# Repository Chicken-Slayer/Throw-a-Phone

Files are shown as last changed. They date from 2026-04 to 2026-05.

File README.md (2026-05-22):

# Throw-a-Phone
Have you ever forgotten your phone at home, and just kept your SIM card along? Me too!
This device aims to solve this common problem faced by us in our daily lives.

In all seriousness, this is a device for people who need absolutely no distractions, or simply a cheap device that can be bought to simply make phone calls without any drama.

## How it works:
Inside the case, there is an ESP32 C3 SUPERMINI, which is compact and affordable - perfect for this use case. Basically, the device uses a 12 key matrix as input, which can be used to enter phone numbers and answer/end calls. The calls are handled using a SIM800L GSM module connected to an external antenna. Due to the hardware used, it can only support 2G networks, which are outdated and may not be available everywhere. 

## PCB:
Here's the Schematic and the PCB:

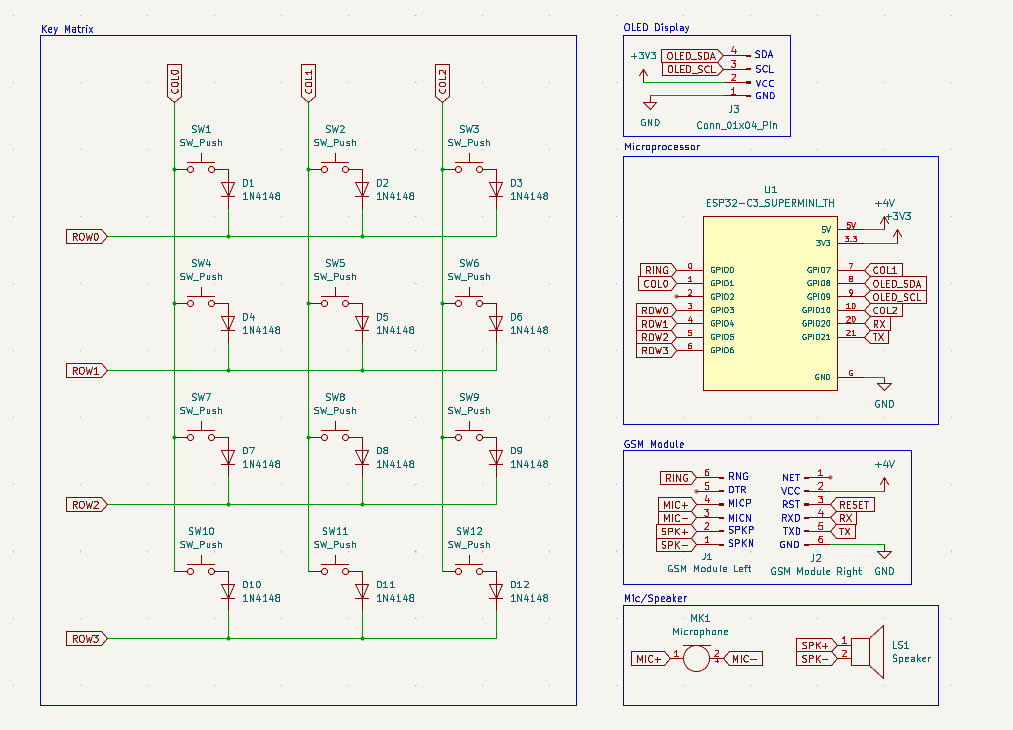
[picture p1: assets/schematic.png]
schematic


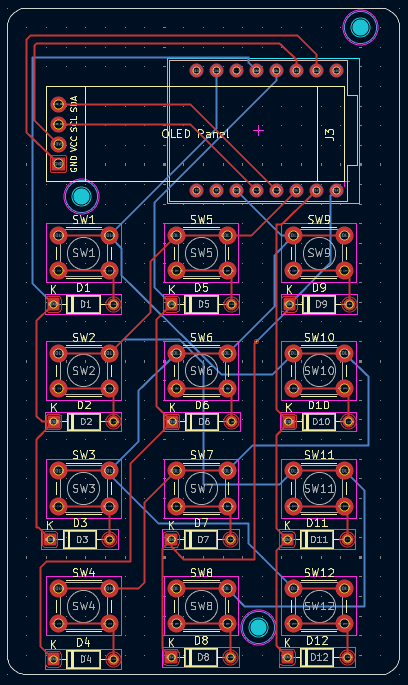
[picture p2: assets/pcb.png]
pcb


## Enclosure:
The components are placed within a 3D printed enclosure. The PCB is held in place with round inserts set in place in both the PCB and the Enclosure. 

It has two separate pieces: 
- The top cover, featuring space for the keys, power switch, screen, and audio I/O
- The base, which has obtrusions designed to hold the PCB in place, as well as clearance for an external antenna and charging port.

The two pieces are secured using hot glue.

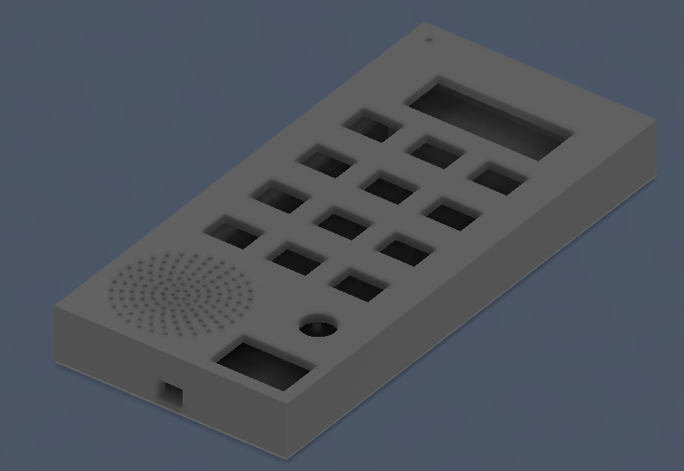
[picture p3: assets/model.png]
model


## Firmware:
The device is coded in C, and makes/receives phone calls by communicating with the GSM module through the UART interface. A key matrix is used to input the numbers and Adafruit libraries are used to control the OLED Display. Different states of the phone have been defined, in which different output is displayed on the OLED.

## Features:
- Making and receiving phone calls

## Replication Guide:
This project is quite easy to replicate hardware-wise, but the software part comes out to be more complicated.
1. Start off by wiring the charging board output to the rocker switch, and then the switch to the ESP32 and the GSM module. The GSM module cannot run on 3.3V supplied by ESP32, so it needs to be powered directly by the battery.
2. Solder the buttons and the OLED display on to the PCB, making sure that the diodes are in the right direction (COL2ROW).
3. Solder the ESP32 module to the PCB and connect the RX, TX and GPIO0 pins to the corresponding ones on the GSM modules.
4. Wire the speaker and the microphone directly to the GSM module and connect the PCB antenna (comes bundled with GSM module).
5. Connect the battery to the charging board power input. Make sure to check polarity.
6. Load up the firmware on to the ESP32 board, making sure to check the pin definitions in the code.
7. Secure the components in place, holding the PCB using the round insertions in the case, and hot gluing remaining components in their respective places. On the top part of the case, space has been given for inserting the microphone, speaker, and rocker switch. There are holes on the bottom part of the case to route the PCB antenna outside and connect the charging module to a USB cable. 

## BOM:
| Product Name | Product Link | Unit Price | Amount | Total  | Remarks |
|---|---|---|---|---|---|
| PCB | https://jlcpcb.com/ | $2.00 | 1 | $11.47 | |
| SIM800L GPRS GSM Module | https://roboticsdna.in/product/sim800l-module/ | $3.10 | 1 | $4.04  | Delivery costs and taxes apply |
| 3.7V 1500 mAh LiPo Battery | https://robu.in/product/1500mah-pcm-protected-micro-li-po-battery | $2.96 | 1 | $2.96  | |
| Tactile Push Button Switch | https://robu.in/product/6x6x5-tactile-push-button-switch | $0.014 | 12 | $0.28  | Only in packs of 10 |
| Microphone | https://robu.in/product/microphone-97mm-pack-of-3 | $0.20 | 1 | $0.58  | Only in packs of 3 |
| TP4056 Li-ion battery charging board | https://robu.in/product/tp4056-1a-lipo-battery-charging-board-micro-usb-with-current-protection | $0.12 | 1 | $0.12  | |
| 28mm Trumpet Speaker | https://robu.in/product/0-5w-8ohm-trumpet-speaker-diameter-28mm | $0.30 | 1 | $0.30  | |
| SPST Rocker Switch | https://robu.in/product/spst-rocker-switch-pack-of-3 | $0.15 | 1 | $0.15  | |
| ESP32-C3 SUPERMINI | https://robu.in/product/esp32-c3-development-board-with-soldering | $2.59 | 1 | $2.59  | |
| 0.91 inch I2C OLED Display | https://roboticsdna.in/product/0-91-inch-iic-4-pin-oled-display-module-ssd1306-white/ | $1.66 | 1 | $2.60  | Delivery costs and taxes apply |
| M2x10mm CSK Countersunk Philips head bolt| https://robu.in/product/easymech-ss-304-csk-countersunk-philips-head-m2-x-10-mm-bolt-25-pcs/| $1.48 | 4 | $1.48  | Only in packs of 25 |
| | | | TOTAL  | $25.09 | |
## Zine:

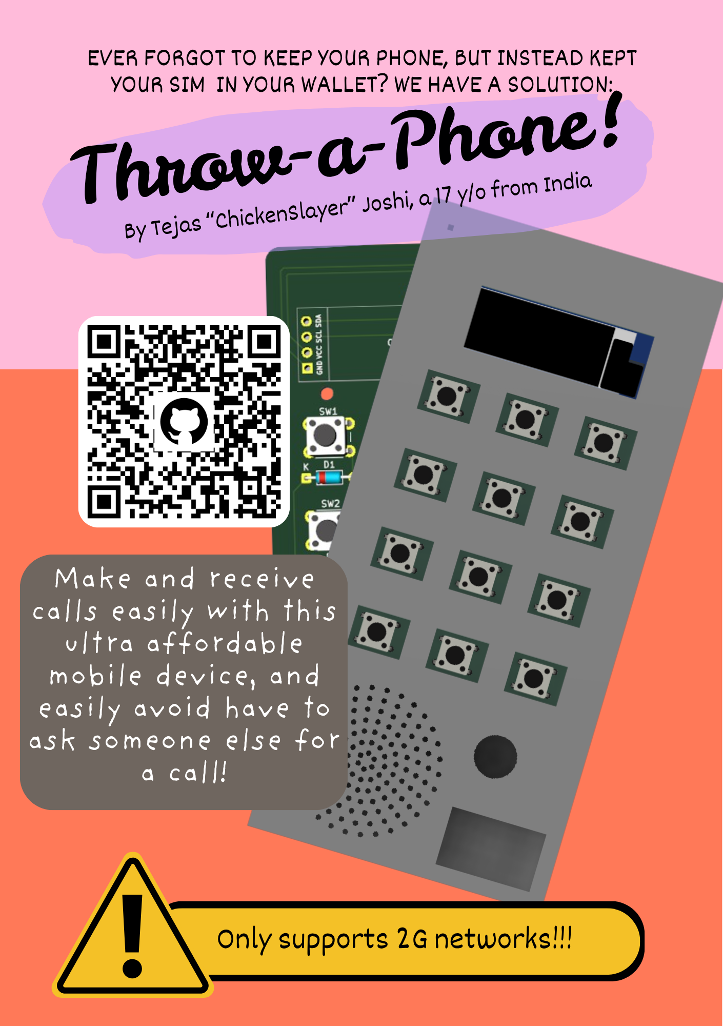
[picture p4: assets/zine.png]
zine


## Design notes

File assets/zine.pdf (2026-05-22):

## EVER FORGOT TO KEEP YOUR PHONE, BUT INSTEAD KEPT YOUR SIM IN YOUR WALLET? WE HAVE A SOLUTION:

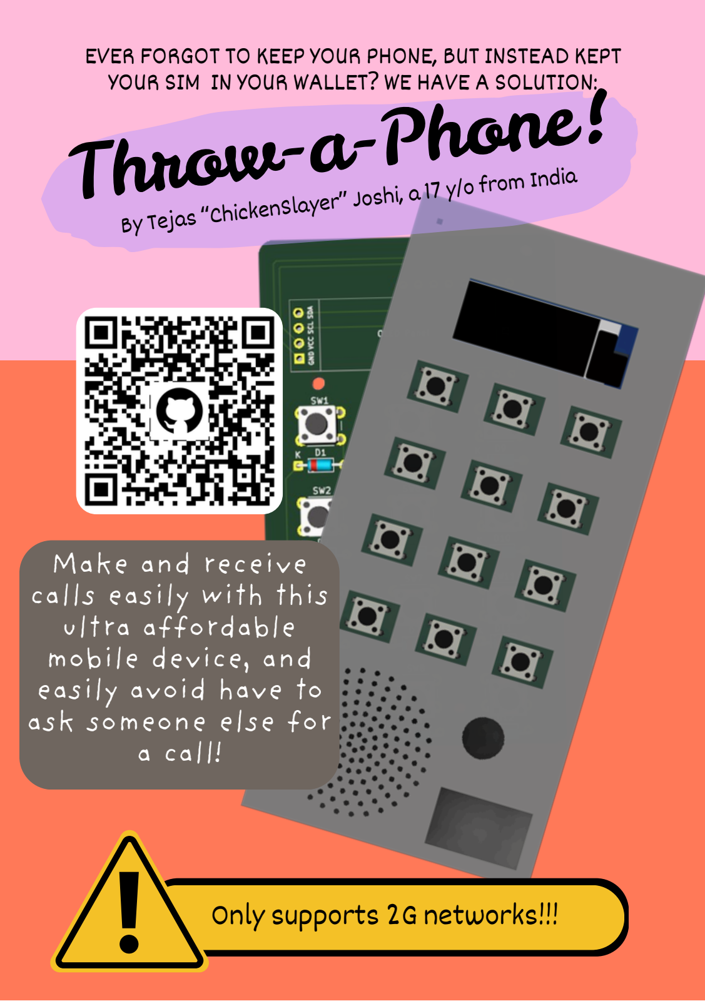
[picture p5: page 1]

Make and receive
calls easily with this
ultra affordable
mobile device, and
easily avoid have to
ask someone else for
a call!

## Only supports 2G networks!!!

# Throw-a-Phone!

## By Tejas

## “ChickenSlayer” Joshi, a 17 y/o from India

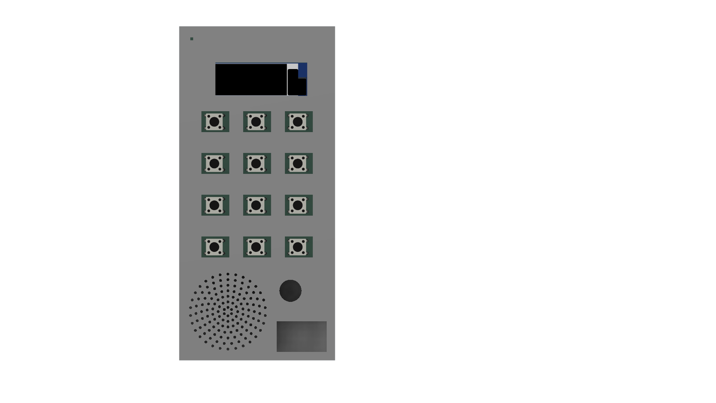
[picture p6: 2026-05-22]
assets/render.png

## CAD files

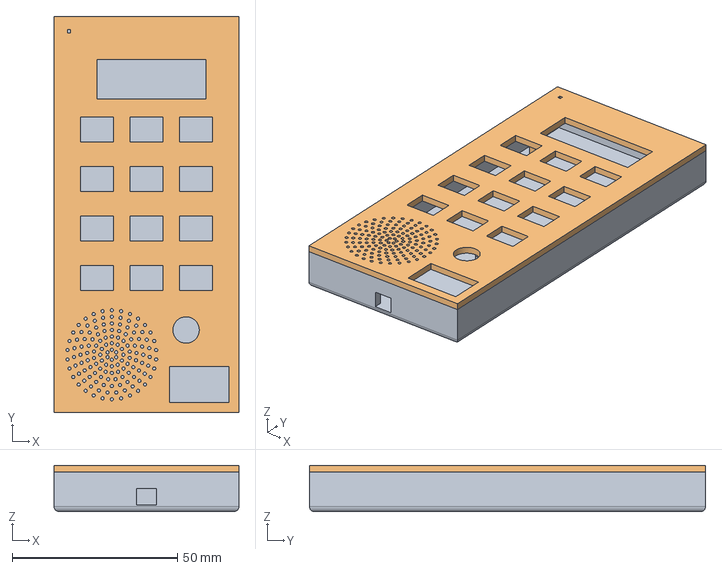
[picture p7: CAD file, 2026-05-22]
Model/Complete.step
56.0 x 120.0 x 14.0 mm

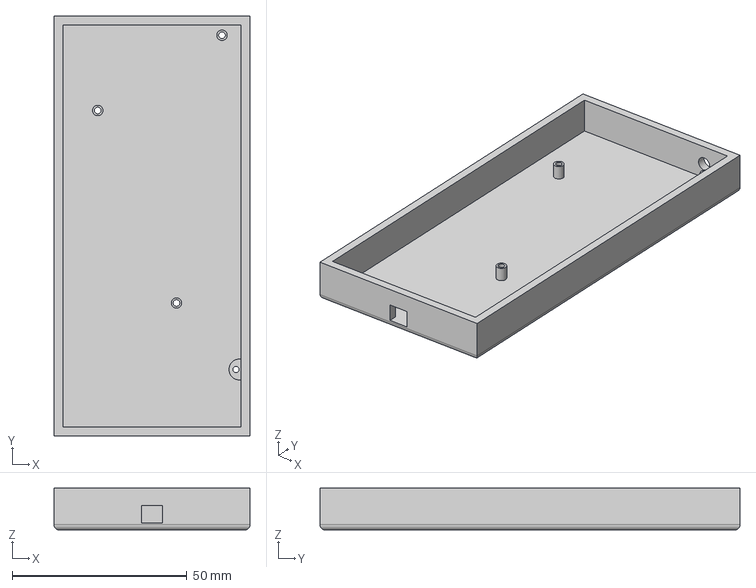
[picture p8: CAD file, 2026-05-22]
Model/Bottom.step
56.0 x 120.0 x 12.0 mm

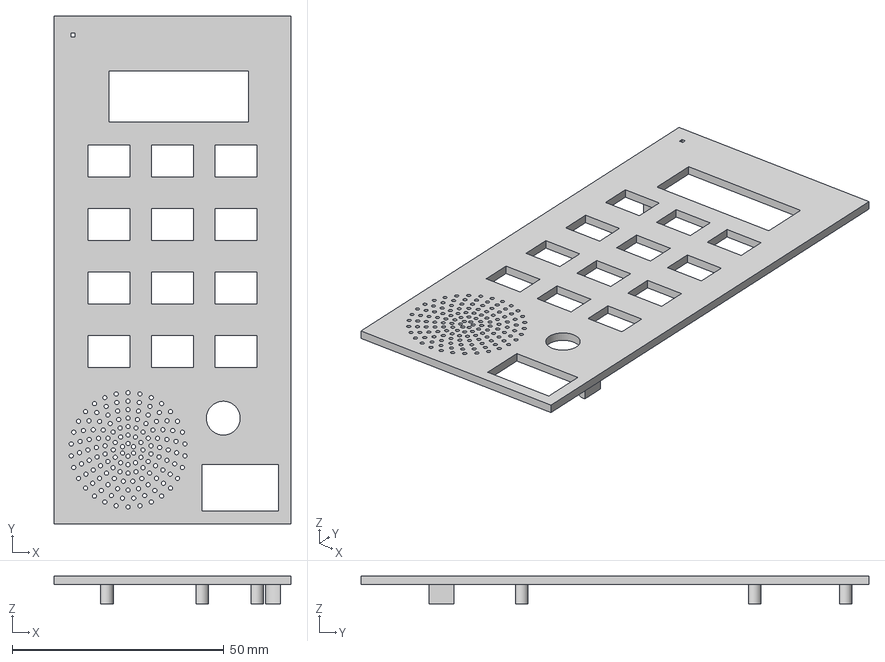
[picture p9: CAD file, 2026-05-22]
production/Top.step
56.0 x 120.0 x 6.50 mm

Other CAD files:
Model/Throw-a-Phone.f3z

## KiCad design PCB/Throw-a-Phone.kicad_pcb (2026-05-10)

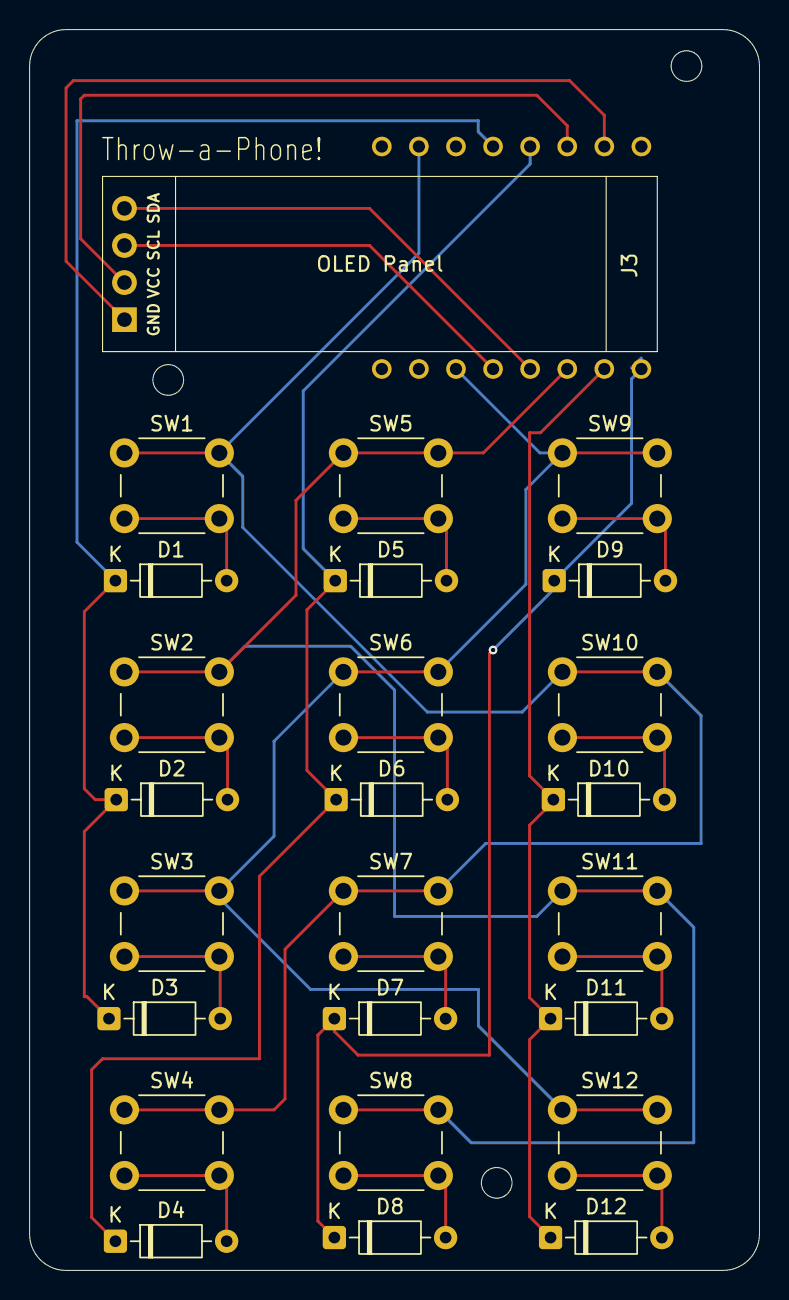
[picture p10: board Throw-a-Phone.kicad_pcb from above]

Board: 2 copper layers, 50.0 x 85.0 mm, 26 parts (1 on the bottom side), 23 nets.

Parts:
D1, D2, D3, D4, D5, D6, D7, D8, D9, D10, D11, D12: 1N4148; D_DO-35_SOD27_P7.62mm_Horizontal
J3: Conn_01x04_Pin; SSD1306-0.91-OLED-4pin-128x32
SW1, SW2, SW3, SW4, SW5, SW6, SW7, SW8, SW9, SW10, SW11, SW12: SW_Push; SW_PUSH_6mm_H5mm
U1: ESP32-C3_SUPERMINI_TH; MODULE_ESP32-C3_SUPERMINI_TH

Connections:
+3V3: J3.2, U1.3.3 (3V3)
COL0: SW1.1, SW4.1, SW7.1, SW10.1, U1.1 (GPIO1)
COL1: SW2.1, SW5.1, SW8.1, SW11.1, U1.7 (GPIO7)
COL2: SW3.1, SW6.1, SW9.1, SW12.1, U1.10 (GPIO10)
GND: J3.1, U1.G (GND)
unnamed: D1.2 (A), SW1.2
unnamed: D2.2 (A), SW2.2
unnamed: D3.2 (A), SW3.2
unnamed: D4.2 (A), SW4.2
unnamed: D5.2 (A), SW5.2
unnamed: D6.2 (A), SW6.2
unnamed: D7.2 (A), SW7.2
unnamed: D8.2 (A), SW8.2
unnamed: D9.2 (A), SW9.2
unnamed: D10.2 (A), SW10.2
unnamed: D11.2 (A), SW11.2
unnamed: D12.2 (A), SW12.2
OLED_SCL: J3.3, U1.9 (GPIO9)
OLED_SDA: J3.4, U1.8 (GPIO8)
ROW0: D1.1 (K), D2.1 (K), D3.1 (K), U1.3 (GPIO3)
ROW1: D4.1 (K), D5.1 (K), D6.1 (K), U1.4 (GPIO4)
ROW2: D7.1 (K), D8.1 (K), D9.1 (K), U1.5 (GPIO5)
ROW3: D10.1 (K), D11.1 (K), D12.1 (K), U1.6 (GPIO6)

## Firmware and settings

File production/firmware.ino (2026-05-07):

/*
Firmware for Throw-a-Phone
By Tejas Joshi "Chicken Slayer"
https://github.com/Chicken-Slayer/Throw-a-Phone
*/

#include <Wire.h>
#include <Adafruit_GFX.h>
#include <Adafruit_SSD1306.h>
#include <SoftwareSerial.h>

// HARDWARE CONFIGURATION:

// display:
#define I2C_SDA 8
#define I2C_SCL 9
#define SCREEN_W 128
#define SCREEN_H 32
#define OLED_RESET -1

Adafruit_SSD1306 display(SCREEN_W, SCREEN_H, &Wire, OLED_RESET);

// GSM Module:
#define SIM_RX 20
#define SIM_TX 21
#define RING 0

SoftwareSerial SIM800L(SIM_RX, SIM_TX);
String simLine = "";

// Key Matrix:
#define ROWS 4
#define COLS 3

const uint8_t ROW_PINS[ROWS] = {3, 4, 5, 6};
const uint8_t COL_PINS[COLS] = {1, 7, 10};

const char KEYMAP[ROWS][COLS] = {
    {'1', '2', '3'},
    {'4', '5', '6'},
    {'7', '8', '9'},
    {'*', '0', '#'}
};

// UART0 is connection to system; UART1 is used for communication to GSM Module

// Phone Configuration:
enum PhoneState {
    ST_IDLE,
    ST_TYPING,
    ST_CALLING,
    ST_INCOMING,
    ST_IN_CALL
};

PhoneState phoneState = ST_IDLE;

String dialingNumber = "";
String callerNumber = "";

// Debounce (limit rate of function execution to improve performance)
unsigned long lastPressTime = 0;
char lastPressKey  = 0;
const unsigned long DEBOUNCE_MS = 220;



// TODO: Properly configure most things:
// - Calling
// - Keys
// - display controls

void setup () {
    Serial.begin(115200);
    Serial.println("[BOOT]Throw-a-Phone starting...")

    // Start display
    Wire.begin(I2C_SDA, I2C_SCL);
    display.setTextColor(SSD1306_WHITE);
    display.clearDisplay();
    display.setTextSize(1);
    display.setCursor(0, 12);
    display.print("Throw-a-Phone initialising...");
    display.display();

    // Starting up the Switch Matrix 
    for (int r = 0; r < ROWS; r++) {
        pinMode(ROW_PINS[r], OUTPUT);
        digitalWrite(ROW_PINS[r], HIGH);
    }
    for (int c = 0; c < COLS; c++) {
        pinMode(COL_PINS[c], INPUT_PULLUP);
    }

    // GSM Module startup
    SIM800L.begin(115200);
    delay(3000);
    SIM800L.println("AT"); 
    updateSerial();
    SIM800L.println("AT+CSQ");
    updateSerial();
    SIM800L.println("AT+CCID");
    updateSerial();
    SIM800L.println("AT+CREG?");
    updateSerial();
    SIM800L.println("AT+CLIP=1");
    updateSerial();
}

void loop() {
    readSIM();

    char key = scanKeys();
    if (key) handleKey(key);

    delay(20);
}


// Note to self: This function is for testing; not to be used in production
void updateSerial() {
    delay(500);
    while (Serial.available())
    {
        SIM800L.write(Serial.read());
    }
    while (SIM800L.available())
    {
        Serial.write(SIM800L.read());
    }
}

void readSIM() {
    while (simSerial.available()) {
        char c = simSerial.read();
        if (c == '\r') continue;  // skip CR
        if (c == '\n') {
        simLine.trim();
        if (simLine.length() > 0) {
            Serial.println("[AT<<] " + simLine);
            processSIMLine(simLine);
        }
        simLine = "";
        } 
        else {
        simLine += c;
        }
  }
}

// Used to scan the key matrix and add the "typing" functionality.
char scanKeys() {
    for (int r = 0; r < ROWS; r++) {
        digitalWrite(ROW_PINS[r], LOW);
        delayMicroseconds(10);

        for (int c = 0; c < COLS; c++) {
            if (digitalRead(COL_PINS[c]) == LOW) {
            char key = KEYMAP[r][c];
            unsigned long now = millis();

            // Accept key if it's a new key or enough time has passed
            bool newKey   = (key != lastPressKey);
            bool debounced = (now - lastPressTime >= DEBOUNCE_MS);

            if (newKey || debounced) {
                lastPressKey  = key;
                lastPressTime = now;
                digitalWrite(ROW_PINS[r], HIGH);

                Serial.printf("[KEY] '%c' pressed\n", key);
                return key;
        }
      }
    }
        digitalWrite(ROW_PINS[r], HIGH);
    }
    lastPressKey = 0;
    return 0;
}

// This function below can seem a little complicated, but it basically just handles the input that we get from the keys on the board.

void handleKey(char key) {
    switch (phoneState) { 
        case ST_IDLE:
            if (key >= '0' && key <= '9') {
                dialNumber = "";
                dialNumber += key;
                phoneState = ST_TYPING;
                updateDisplay();
            }
            break;

        case ST_TYPING:
        if (key >= '0' && key <= '9') {
            if (dialNumber.length() < 15) {
                dialNumber += key;
                updateDisplay();
            }
        } else if (key == '#') {
        // Backspace
            if (dialNumber.length() > 0) {
                dialNumber.remove(dialNumber.length() - 1);
            }
            if (dialNumber.length() == 0) {
                phoneState = ST_IDLE;
            }
            updateDisplay();
        } else if (key == '*') {
        // Dial
            if (dialNumber.length() > 0) {
                makeCall(dialNumber);
            }
        }
        break;

        case ST_CALLING:
            if (key == '#') {
                hangUp();
            }
            break;

        case ST_INCOMING:
            if (key == '*') {
                answerCall();
            } else if (key == '#') {
                hangUp();
            }
            break;


        case ST_IN_CALL:
            if (key == '#') {
                hangUp();
            }
            break;
    }
}

// GSM Module control (No access to actual device so far, might end up a buggy mess if I write code without testing on it.)
void processSIMLine(const String& line) {

  // Incoming call to our phone
  if (line == "RING") {
    if (phoneState == ST_IDLE || phoneState == ST_TYPING) {
      callerNumber = "";        // Will be filled once +CLIP arrives
      phoneState = ST_INCOMING;
      updateDisplay();
    }
    return;
  }

  // CLIP stands for Calling line identification presentation, basically identification of the caller.
  if (line.startsWith("+CLIP:")) {
    int q1 = line.indexOf('"');
    int q2 = line.indexOf('"', q1 + 1);
    if (q1 >= 0 && q2 > q1) {
      callerNumber = line.substring(q1 + 1, q2);
    }
    if (phoneState != ST_INCOMING) {
      phoneState = ST_INCOMING;
    }
    updateDisplay();
    return;
  }

  // If call is picked up by the receiver
  if (line.startsWith("+COLP:")) {
    phoneState = ST_IN_CALL;
    updateDisplay();
    return;
  }

  // When call ends
  if (line == "NO CARRIER" || line == "BUSY" || line == "NO ANSWER"  || line == "ERROR") {
    resetToIdle();
    return;
  }

  // When we end the call 
  if (line == "OK" && phoneState == ST_IDLE) {
    return;
  }
}


// Call functions: Just to keep things simplified in the above complicated mess
void makeCall(const String& number) {
    Serial.println("[CALL] Dialling " + number);
    phoneState = ST_CALLING;
    updateDisplay();
    SIM800L.println("ATD" + number + ";");
    updateSerial();
}

void answerCall() {
    Serial.println("[CALL] Answering");
    phoneState = ST_IN_CALL;
    updateDisplay();
    SIM800L.println("ATA");
    updateSerial();
}

void hangUp() {
    Serial.println("[CALL] Hanging up");
    SIM800L.println("ATH");
    updateSerial();
    resetToIdle();
}

void resetToIdle() {
    phoneState   = ST_IDLE;
    dialNumber   = "";
    callerNumber = "";
    updateDisplay();
}

// Display stuff
// This looks longer but perhaps one of the easier parts to understand and write

void drawHint(const char* hint) {
    display.setTextSize(1);
    display.setCursor(0, 24);
    display.print(hint);
}

void drawNumber(const String& num) {
    bool large = (num.length() <= 10);
    display.setTextSize(large ? 2 : 1);
    int charW = large ? 12 : 6;
    int x = max(0, (SCREEN_W - (int)num.length() * charW) / 2);
    int y = large ? 8 : 12;
    display.setCursor(x, y);
    display.print(num);
}

void updateDisplay() {
    display.clearDisplay();
    display.setTextColor(SSD1306_WHITE);

    switch (phoneState) {

        case ST_IDLE:
            display.setTextSize(1);
            display.setCursor(38, 4);
            display.print("READY");
            display.setCursor(16, 20);
            display.print("Enter number...");
            break;

        case ST_TYPING:
            drawHint("* Call      # Del");
            drawNumber(dialNumber);
            break;

        case ST_CALLING:
            display.setTextSize(1);
            display.setCursor(30, 0);
            display.print("Calling...");
            drawNumber(dialNumber);
            drawHint("     # Cancel");
            break;

        case ST_INCOMING:
            display.setTextSize(1);
            display.setCursor(20, 0);
            display.print("Incoming Call");
            drawNumber(callerNumber.length() > 0 ? callerNumber : "Unknown");
            drawHint("* Answer   # Decline");
            break;

        case ST_IN_CALL: {
            display.setTextSize(1);
            display.setCursor(38, 0);
            display.print("In Call");
            String activeNum = (dialNumber.length() > 0) ? dialNumber : callerNumber;
            drawNumber(activeNum.length() > 0 ? activeNum : "Unknown");
            drawHint("       # Hang Up");
            break;
        }
    }

    display.display();
}

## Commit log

2026-03-29 Designed Schematic
    [Throw-a-Phone.kicad_pcb, Throw-a-Phone.kicad_sch]
2026-04-04 Made PCB, fixed design
    [Throw-a-Phone.kicad_pcb, Throw-a-Phone.kicad_sch]
2026-04-19 Made enclosure, edited PCB
    [Bottom.step, Bottom.stl, Throw-a-Phone.kicad_pcb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]
2026-04-21 Updated readme, added images. Fixed PCB edge cuts
    [Complete.step, Throw-a-Phone.kicad_pcb, Throw-a-Phone.kicad_sch]
2026-04-26 Added zine page, removed old. Added 3D model.
    [Bottom.stl, Throw-a-Phone.f3d, Top.stl]
2026-04-27 Update PCB, readme. Create gerbers
    [BOM.csv, Bottom.step, Throw-a-Phone.kicad_pcb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]
2026-04-27 Update BOM
    [BOM.csv]
2026-04-27 Fix quantities in BOM
2026-04-27 Update BOM, changed directory
    [BOM.csv]
2026-04-27 Fix BOM final
    [BOM.csv]
2026-05-10 Fix directory nesting
    [PCB.step, Throw-a-Phone.kicad_pcb, Throw-a-Phone.kicad_sch]
2026-05-22 Update README, change zine
    [Bottom.step, Complete.step, PCB.step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]
2026-05-22 Add CAD design for production
    [Bottom.step, Complete.step, PCB.step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]
